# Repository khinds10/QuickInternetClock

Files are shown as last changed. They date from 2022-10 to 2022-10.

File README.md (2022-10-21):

# ESP32 Quick Internet Clock (automatic timeset)
ESP32 Internet Clock, Handsfree sets time automatically.

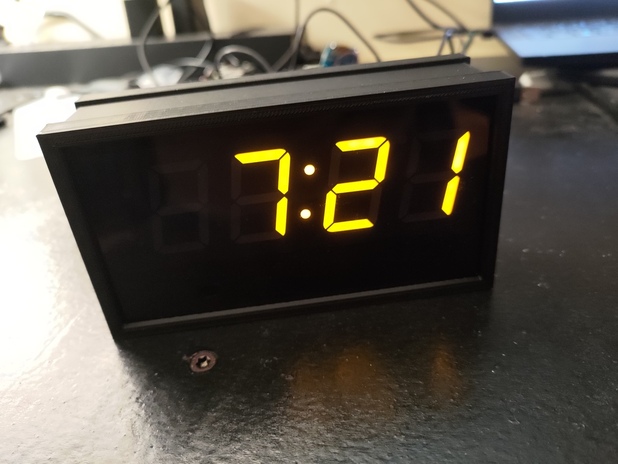
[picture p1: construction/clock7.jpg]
clock7


**Clone Project**
From github download/clone the project to get started

https://github.com/khinds10/QuickInternetClock

**3D Printing:**

From the "3D Print" folder print 1 back panel, 1 case, 2 edges and 1 front panel.

**Supplies Needed**

1.2" 7 Segment Display

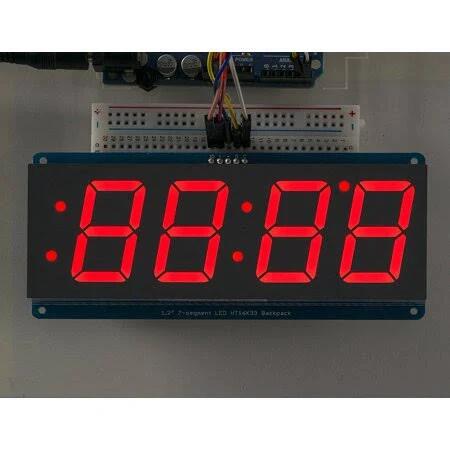
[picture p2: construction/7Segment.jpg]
7 Segment


ESP DEV KIT v1

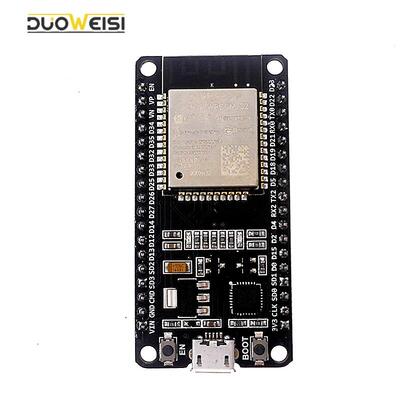
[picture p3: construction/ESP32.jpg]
ESP32


OTG USB Splitter (display needs 5V Power)

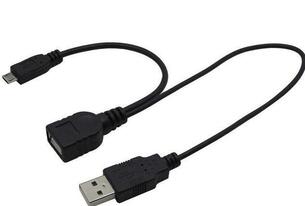
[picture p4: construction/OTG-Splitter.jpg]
OTG-Splitter


Polycarbonate-Semi-Transparent (smoke gray)

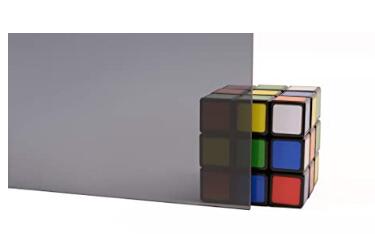
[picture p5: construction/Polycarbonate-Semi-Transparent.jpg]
Polycarbonate-Semi-Transparent


**Wiring:**

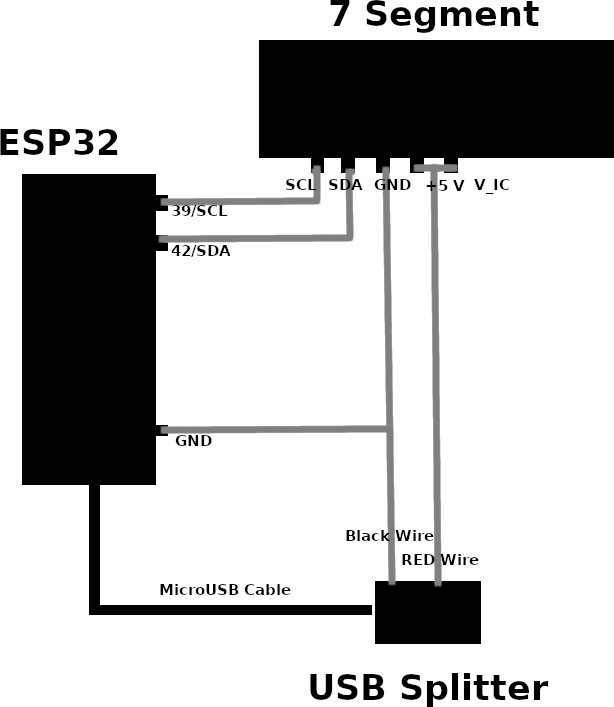
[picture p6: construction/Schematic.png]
Schematic


Connect the SCL/SDA Pins from the display to the ESP32.

Connect the RED and BLACK wires from the USB split cable to the GND and +5 and V_IO pins of the display, it needs a full 5V of power to work.

Connect the GND of the ESP32 to the GND of the Display as well.

Solder and connect the Pins according the schematic.

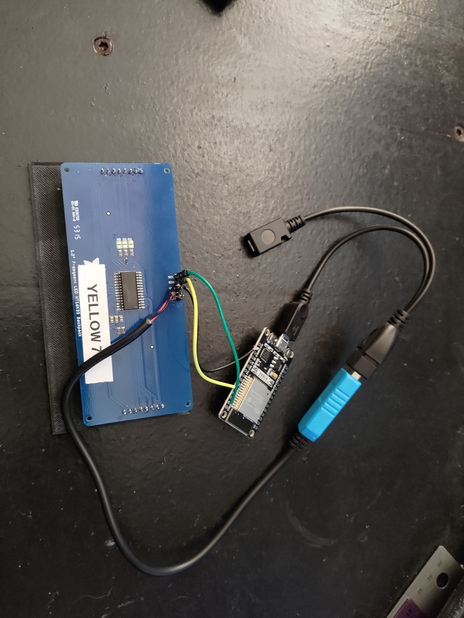
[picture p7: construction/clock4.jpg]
clock4


Gather the 3D printed panels and assemble as follows, you'll need to cut the plexiglass to fit the frame.

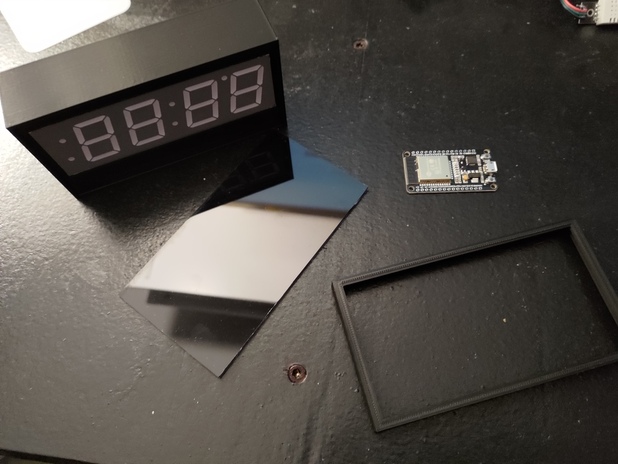
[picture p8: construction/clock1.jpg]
clock1


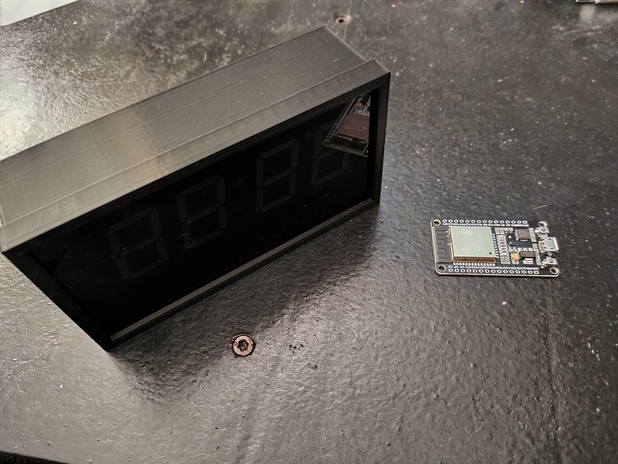
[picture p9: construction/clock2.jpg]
clock2


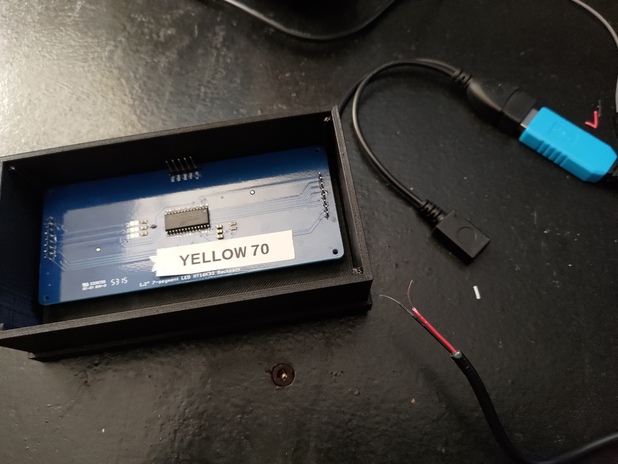
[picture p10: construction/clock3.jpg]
clock3


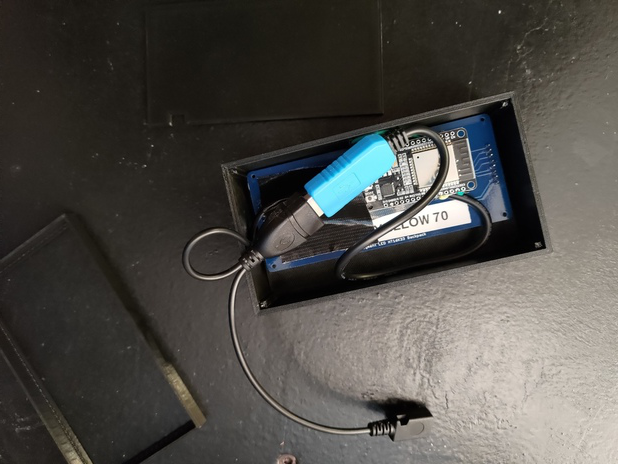
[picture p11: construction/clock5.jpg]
clock5


Attach the back frame and panel cover with the female OTG usb cable extended to plug in to the power supply.

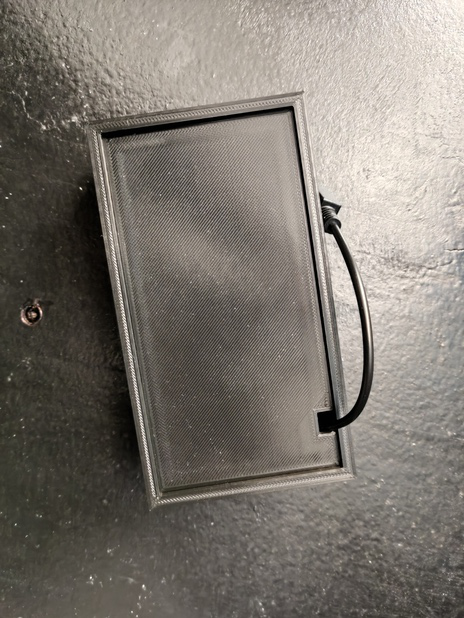
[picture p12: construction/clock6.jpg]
clock6


**Flash the ESP32**

 Load the project folder (which you've checked out) to Visual Studio Code (this is free software).  

***IMPORTANT***

Copy the src/settings-default.h to settings.h and adjust your `ssid` , `password` variables to your own WiFi connection.

Adjust `gmtOffset_sec` as a number of seconds different from Greenich Mean Time.  Looks like -18000 seconds is -5 hours for the timezone of America/Eastern Standard.

Plug the ESP32 USB to the computer USB and build/deploy the project.

NOTE: a lot of times you have to plug the ESP32 directly to the computer and not use the USB splitter, it's interfering with the deploy process to the ESP32, after flashing, plug it back to the USB splitter so the ESP and the 7 Segment are all connected to USB power correctly.

**Finished!**

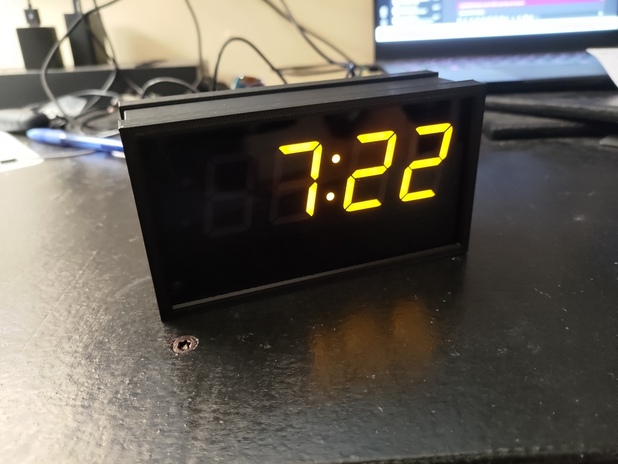
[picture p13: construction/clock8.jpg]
clock8


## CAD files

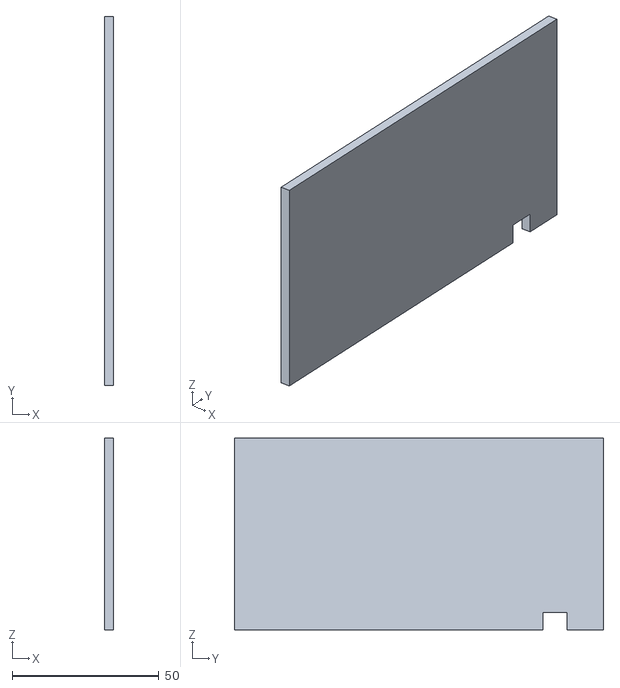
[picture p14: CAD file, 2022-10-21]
3D Print/back.stl
3.00 x 126.0 x 65.5

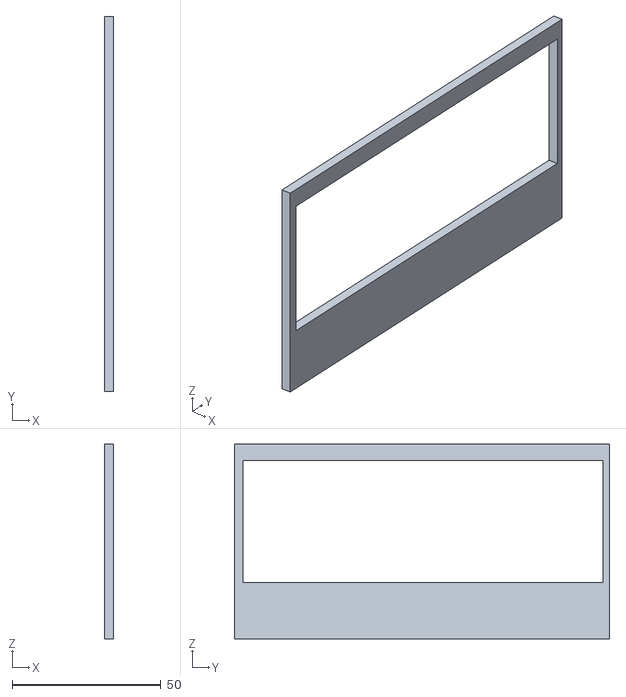
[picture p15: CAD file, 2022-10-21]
3D Print/front.stl
3.00 x 126.0 x 65.5

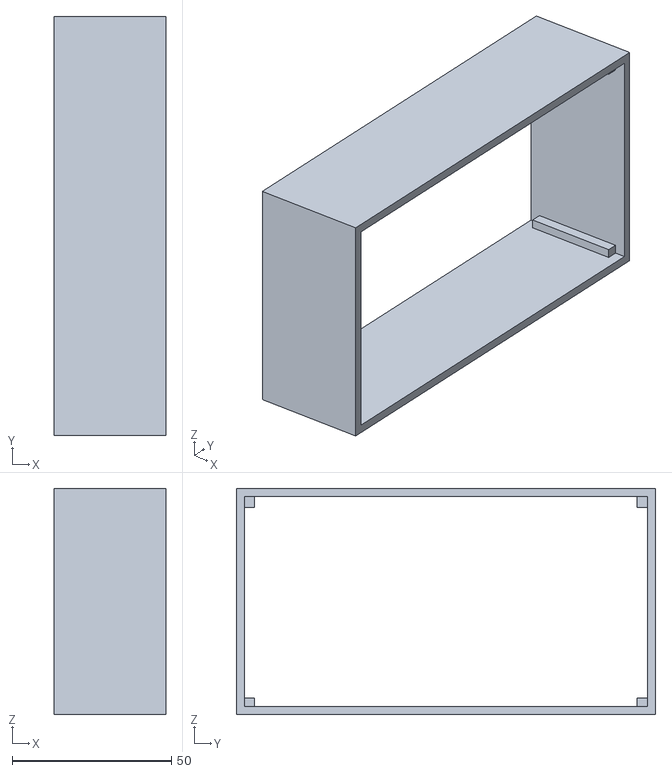
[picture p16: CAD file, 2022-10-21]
3D Print/case.stl
35.0 x 131.5 x 71.0

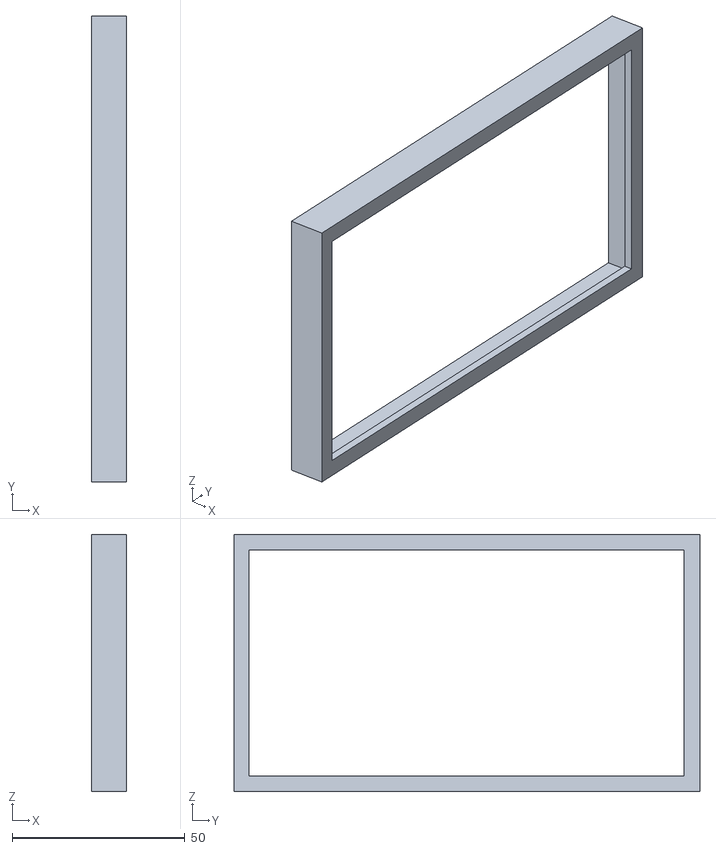
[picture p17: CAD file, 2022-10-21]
3D Print/edge.stl
10.0 x 135.0 x 74.5

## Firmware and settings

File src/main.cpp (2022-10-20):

#include <WiFi.h>
#include "time.h"
#include <Wire.h>
#include <string>
#include <settings.h>
#include <internet/wifi.h>
#include <internet/ntp.h>
#include "HT16K33.h"
HT16K33 seg(0x70);

void setup() {
  Serial.begin(115200);

  // begin WiFi connection
  initWiFi();
  Serial.print("RRSI: ");
  Serial.println(WiFi.RSSI());

  // init and get the time
  configTime(gmtOffset_sec, daylightOffset_sec, ntpServer);

  // 7 segment display init
  seg.begin();
  Wire.setClock(100000);
  seg.displayOn();
  seg.brightness(4);
  seg.setDigits(4);
}

void loop() {
  
  // show 12 hour time
  time_t curr_time;
  curr_time = time(NULL);
  tm *tm_local = localtime(&curr_time);
  if (tm_local->tm_hour > 12) tm_local->tm_hour = tm_local->tm_hour - 12;
  if (tm_local->tm_hour == 0) tm_local->tm_hour = 12;
  seg.displayTime(tm_local->tm_hour, tm_local->tm_min, true, false);
}

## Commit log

2022-10-21 Added Schematic
2022-10-21 resize images, add the STL 3D print files
    [back.stl, case.stl, edge.stl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]
